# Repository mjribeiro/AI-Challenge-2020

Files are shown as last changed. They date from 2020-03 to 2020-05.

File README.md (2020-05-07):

# Citizen Data Science: Exploring the use of machine learning for a public network of low-cost air quality devices

Might add/change this information to be about our project specifically, but for now I think the general description and some assignment guidelines should be helpful for keeping track of deadlines and structuring submissions :)

## Assignment Description
This is the repository for the report and code for a group project for the CM50304 unit. The provided coursework description is as follows:

> As  a  group  you  will  need  to  choose  a  challenge related  to  artificial  intelligence  (AI), propose  a  solution  to  it, develop  a  prototype  or  a  proof  of  concept for  this  solution,  and  critically evaluate  this  solution  in  terms  of  how  it  meets  accountability,  responsibility  and  transparency concerns. 
>
> It can be a challenge in AI development such as challenges in ensuring fairness in AI decisions, or it can be a societal challenge that can be solved with AI such as dangerous search and rescue operations that can be performed by robots, or it can be a societal challenge created by AI such as challenges in ensuring truth in media content in the presence of deepfakes and news articles generated by AI.
>
> The choice of challenges is unlimited as long as you can justify that this is an important challenge for the society. It can be either directly essential to the society because, for example, it addresses urgent societal needs, or the challenge may be important indirectly to society because, for example, solution of this challenge would improve business processes and as a consequence it would bring improvements for the overall society.

## Assessments
|Task |% of Mark | Date & Time |Done? (Y/N)| 
|---|---|---|---|
|Prototype |0? |20/04/2020, 17:15 |Y |
|Prototype Demo|20 |04/05/2020, 14:15-16:05|Y | 
|Written Report|80 |08/05/2020, 16:00 |Y | 

### Demo and Presentation (20%)
Maximum 5 min demonstration of prototype, followed by 20 min presentation with 5 min of questioning. The presentation should cover:
* What is the challenge and why it is important
* What is the state of the art for this challenge
* What is the solution
* What is the prototype
* What is the future work to develop the whole solution
* How does the solution meet accountability, responsibility and transparency concerns

### Written report (80%)
The report should follow this structure:
1. **Title and list of team members** (*1 page*) – the report should not be anonymous because the project would be demonstrated in person in advance
2. **Problem specification of the challenge** (*0.5 – 1 page*) – this section should state the challenge, motivate why this challenge is important and explain how it relates to AI
3. **State of the art review** (*2 – 3 pages*) – this section should review the existing solutions for this challenge and critical analyse ethical issues related to them. It maybe the case that there are no existing solutions for the  chosen challenge. In this case this should be clearly stated and analysed why it is so. If applicable, existing solutions for related challenges may be reviewed here. For example, if your solution is based on solutions for other challenges you  should review and critically analyse them in this section.
4. **Whole solution description** (*1 – 3 pages*) – this section should explain your ambitious solution and why it requires or why it benefits from the interdisciplinary approach. If the solution involves novel research the section should explain why you believe that this research is likely to be successful in the foreseeable future (see above).
5. **Prototype description** (*3 – 10 pages*) – this section should explain the scope of your developed prototype, explain how it  works and how it relates to the whole solution. It should clearly demonstrate the interdisciplinary effort in this development. If interdisciplinary development was not possible (see above) it should be clearly stated in this section and explain why it was not possible to exploit some of the expertise from members of your group. This section should also reflect how the experience of  developing this prototype has confirmed or questioned your whole solution and how it may have changed your view on the whole solutionor possiblythe challenge in general.
6. **Plan for the future work to develop the solution** (*0.5 – 1 page*) – this section should describe immediate and long-term steps after development of the prototype that should be made to achieve  the  whole  solution. If during development of prototype or  critical  reflection  of  the solution you come to the conclusion that the proposed solution is not useful or not ethically responsible or the overall challenge should not  be formulated in this way (see  above), this section should clearly state this case and may omit description of future work.
7. **Critical reflection of the solution** (*1 – 3 pages*) – this section should provide an analyse how the proposed solution  meets  accountability,  responsibility,  transparency  and  other  ethical concerns. It should honestly reflecton both positive and  negative impac  the solution may ave.If the view from the ethical perspective on the solution has changed during the work on this project this section should describe that and explain why the view has changed.
8. **Teamwork  process  description**  (*2 – 3  pages*) – this section should  describe how your group organised teamwork, what communication channels and collaboration tools you used, how you distributed the tasks, what process allowed you to learn from another discipline during this project.
9. **Lessons learnt**  (*1 – 2 pages*) – this section should reflect on the whole project from the teamwork perspective: what was done well, what could have been improved, what would you change if you were to work on another project in this group, what could you recommend for an interdisciplinary team.
10. **Individual   contributions**   (*1 – 2 pages*) – this section should briefly state individual contributions from each team member.
11. **Lessons learnt from another discipline** (*0.5 – 1 page per person*) – each member of the group should state what they learnt from another discipline during this project.

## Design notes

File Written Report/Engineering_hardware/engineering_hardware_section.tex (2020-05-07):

\subsection{Device}

%\subsection{Design Requirements:}

\textbf{Design Specification}\\

% Table generated by Excel2LaTeX from sheet 'Sheet1'
\begin{table}[htbp]
  \centering
  \caption{Add caption}
\resizebox{\textwidth}{!}{\begin{tabular}{lccll}
\hline
    \multicolumn{1}{c}{No.}&{Requirement} & Wish/Deman & \multicolumn{1}{p{10.785em}}{Importance} & \multicolumn{1}{c}{Engineering Specification}  \\
          &       & \multicolumn{1}{p{8.785em}}{ (1 low, 5 high)} &       &  \\
\hline
1& Sensors open to atmosphere & D & & \\
2&Water Proof & D & & IP67 \\
3&Long battery life & W & 4 & Self powered + battery capacity. > 1 week battery life \\
4&Easy to set up & W & 5 & \\
5&Durable & W & 4 & Sustain accidental drops from height 0.5m \\
6&Low cost & W & 3 & Component and raw material cost < £200 \\
7&Recylable & W & 2 & \\
8&Transparent & W & 4 & \\
9&Easy to charge & W & 2 & Clear acess to charging port \\
10&Cheap to manufacture & W & 3 & Manufacture and assembly cost < £30 \\
11&Small form factor & W & 3 & Overall dimmensions 30x30x30cm \\
\hline
\end{tabular}}%
\label{tab:specification}
\end{table}%

Long Battery Life (4):\\
To ensure regular air quality measurements minimum intervention with the device is required. The most involved element is the charging of the device, therefore this should be kept to a minimum by having a long battery life.
\vskip 0.1in
Easy to set up (5):\\
Crucial to ensuring a citizen science approach to monitoring air quality is maintaining a very simple set up of the sensor. As stipulated in the background the device must be portable and thus require 'packing up' and 'setting up'. Therefore both of these processes must be intuitive (completable without any training or instruction).
\vskip 0.1in
Durable (4):\\
Due to the portable nature of the sensor, and to ensure longevity, the device must be durable to general wear and tear. This has the added benefit of reducing the cost of the air monitoring system by extending the useable life of each sensor.
\vskip 0.1in
Low Cost (3:)\\
In line with the goals of a low cost widely distributed sensor network, the manufacture and component costs must be kept to a minimum to ensure affordability of the device.
\vskip 0.1in
Recyclable (2):\\
In line with responsible use of AI the physical device should not contribute to environmental concerns. This will be achieved by avoiding non-recyclable materials in the design process where possible. These include styrofoam, black plastics and bi-material composites which are hard to separate in the recycling process.
\vskip 0.1in
Transparent (4):\\
The concept of transparent AI can also be extended to the physical device. Ability to view the electronics will demonstrate there are no other devices present such as camera and microphones. An accompanying schematic could be displayed on the website on which the air quality data is displayed. This would detail the components and their purposes in lay terms, which the transparent device would then allow confirmation upon inspection.
\vskip 0.1in
Easy to charge (2):\\
To engage in citizen science effectively, the device should be easy to charge.
\vskip 0.1in
Cheap to manufacture (3):\\
In addition to component cost, the manufacture methods can add considerable cost. Therefore the design should incorporate modularity and simplicity resulting in a minimum number of different manufacturing processes to reduce cost.
\vskip 0.1in
Small form factor (3):\\
The device must be suitable for a variety of different locations, and not take up valuable garden or indoor space.\\
\vskip 0.1in
\textbf{Concepts}\\

A wide variety of concepts were generated using a brainstorming approach. Different design cues and ideas were incorporated into four overall concepts, these are displayed below with key features labelled:

\begin{figure}[H]
\centering
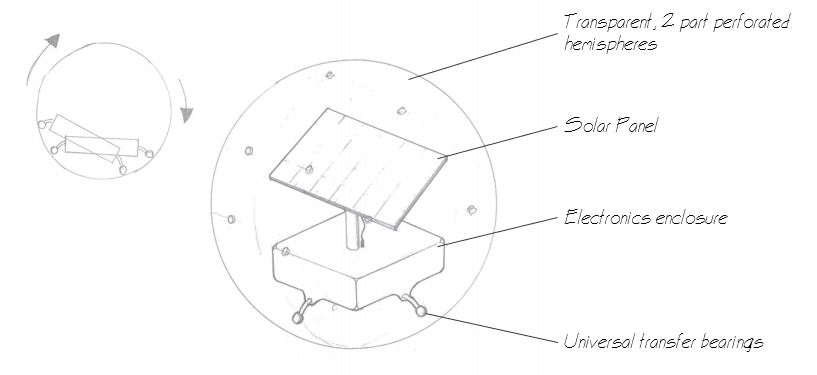
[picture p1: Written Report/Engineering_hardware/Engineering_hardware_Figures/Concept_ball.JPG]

\caption{\textbf{Concept A:} A clear sphere surrounds the sensor hardware, the symmetry of the sphere allows the sensors to move within the protective casing. This concept is focused on the specification requirement for easy setup, the self-levelling mechanism ensures a solar panel for charging is always facing up to the light, whilst sensors can be open to the environment and protected from rain by always facing down. }
\label{fig:concept_A}
\end{figure}

\begin{figure}[H]
\centering
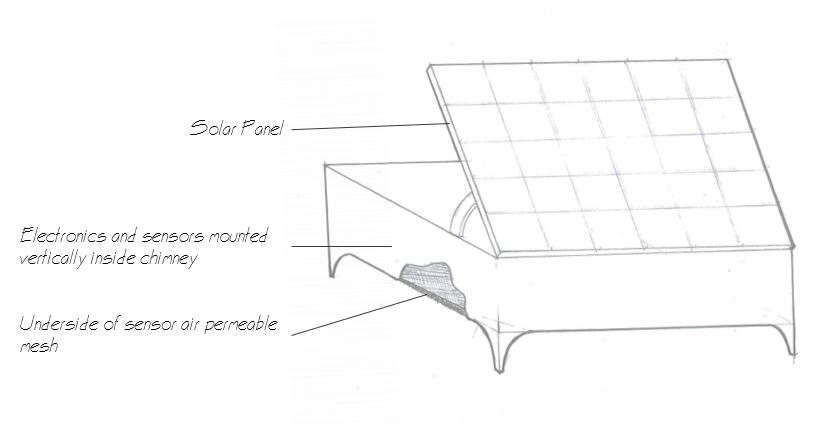
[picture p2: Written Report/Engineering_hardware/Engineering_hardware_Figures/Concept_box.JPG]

\caption{\textbf{Concept B:} A solid box contains the sensors, open to the environment and protected from water ingress by a casing raised on small legs. This concept is focused on the specification requirement for low cost; at each stage the design was simplified as much as possible to reduce component cost and simplify the manufacturing and assembly.}
\label{fig:concept_B}
\end{figure}

\begin{figure}[H]
\centering
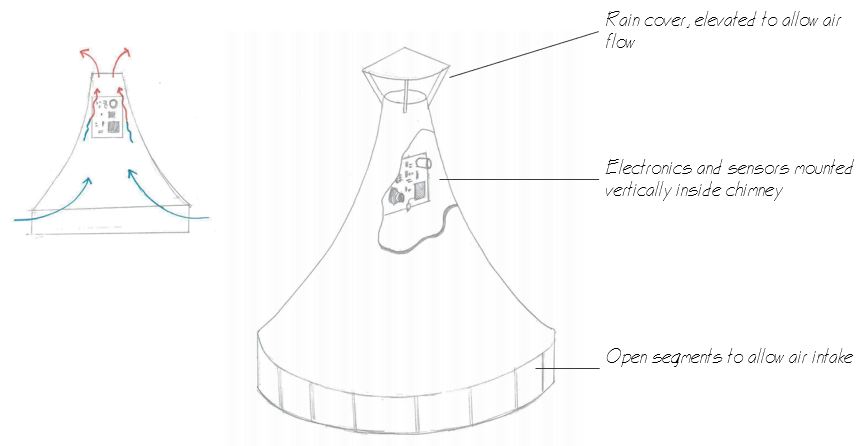
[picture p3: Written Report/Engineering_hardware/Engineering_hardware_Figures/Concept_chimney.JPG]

\caption{\textbf{Concept C:} The electronics and sensors are encased in a chimney-like structure. This concept was inspired by using natural convection currents driven by heat given off by the electronics to drive air past the sensors. This solution would be an energy-efficient method for making accurate measurements without the use of an electric fan.}
\label{fig:15cm_shell_loading}
\end{figure}

\begin{figure}[H]
\centering
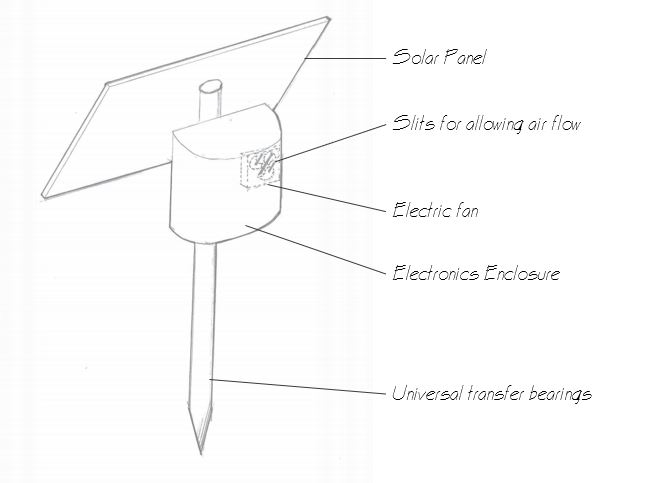
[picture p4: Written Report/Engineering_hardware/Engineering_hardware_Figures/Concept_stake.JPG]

\caption{C\textbf{Concept D:} A protective case houses the sensors and electronics, a larger solar panel is used to power an electric fan which feeds air into the sensors. This design is a larger more robust concept of an air quality monitor with a less portable design.}
\label{fig:15cm_shell_loading}
\end{figure}

The four concepts described were then scored against the design criteria specified in table \ref{tab:specification}. The "demand" categories were simple boolean pass-fail criteria. The "wish" categories were given a numeric score 1-5 with five being the best dependant on how well the concept met the specification, this was weighted by the importance of each specification point and summed to give an overall score.

% Table generated by Excel2LaTeX from sheet 'Sheet1'
\begin{table}[htbp]
  \centering
  \caption{Add caption}
    \begin{tabular}{lrrrr}
          & \multicolumn{4}{c}{Concepts} \\
\hline
    Spec No. & \multicolumn{1}{l}{A} & \multicolumn{1}{l}{B} & \multicolumn{1}{l}{C} & \multicolumn{1}{l}{D} \\
\hline
    \multicolumn{1}{r}{1} & 1     & 1     & 1     & 1 \\
    \multicolumn{1}{r}{2} & 1     & 1     & 1     & 1 \\
    \multicolumn{1}{r}{3} & 3     & 5     & 2     & 4 \\
    \multicolumn{1}{r}{4} & 5     & 4     & 3     & 1 \\
    \multicolumn{1}{r}{5} & 5     & 3     & 4     & 3 \\
    \multicolumn{1}{r}{6} & 4     & 5     & 2     & 3 \\
    \multicolumn{1}{r}{7} & 3     & 3     & 3     & 3 \\
    \multicolumn{1}{r}{8} & 5     & 4     & 5     & 3 \\
    \multicolumn{1}{r}{9} & 3     & 5     & 3     & 4 \\
    \multicolumn{1}{r}{10} & 3     & 4     & 2     & 3 \\
    \multicolumn{1}{r}{11} & 4     & 4     & 3     & 2 \\
    weighted sum & \cellcolor[rgb]{ .388,  .745,  .482}127 & \cellcolor[rgb]{ .427,  .757,  .486}126 & \cellcolor[rgb]{ .98,  .616,  .459}96 & \cellcolor[rgb]{ .973,  .412,  .42}86 \\
\hline
    \end{tabular}%
  \label{tab:addlabel}%
\end{table}%

The weighted comparison between concepts revealed that concept A was most suitable for fulfilling the design brief. Prototype B was very close in the overall score however prototype A was perceived to have a few key advantages:
\begin{itemize}
\item A round spherical casing has no localised stress concentrations as opposed to a more angular geometry of prototype B. The sensor would be more robust to impact fractures that it would be exposed to from being dropped.
\item Concept A has a significantly more appealing design in terms of interesting aesthetic and movable internal parts. Although hard to quantify and therefore not included as design criteria, engaging design is more likely to interest the public for citizen science initiatives.
\item The self-levelling design of concept A, although adding some cost ensures the sensor cannot be setup incorrectly, the reliability of readings that this would likely produce is likely to outweigh a small increase in cost.
\end{itemize}

%prototypes for each mechanism:
%locking two parts together

\textbf{Prototype}\\

A prototype was designed and built to test the suitability of the design, the form of the device was designed as a single 3d printed piece. 3d printing is an industry-standard for rapid prototyping, a PLA plastic material was used due to its low melting point and hence high-quality finish. An "off the shelf" Polystyrene, transparent, 180 mm diameter sphere was specified for the casing:
\begin{figure}[H]
\centering
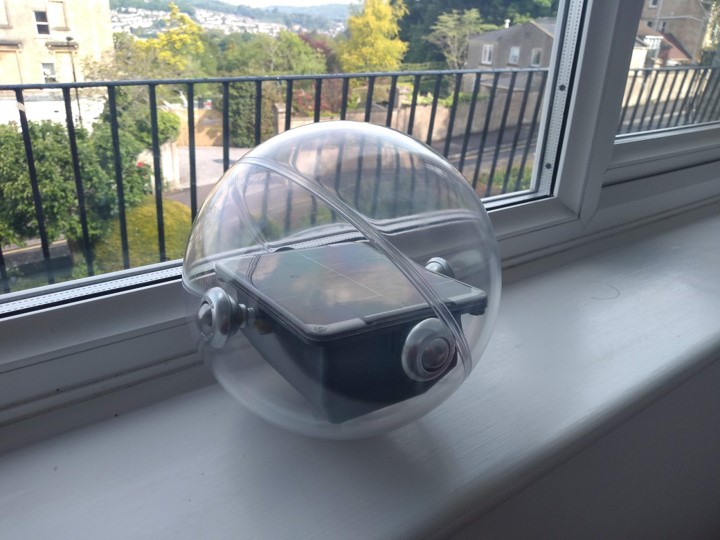
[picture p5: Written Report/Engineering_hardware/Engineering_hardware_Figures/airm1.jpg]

\caption{The physical prototype, displayed in a typical setting on a window sill.}
\label{fig:15cm_shell_loading}
\end{figure}

A 6W solar panel was chosen as the maximum surface area that could be accommodated by a device of this size. The prototype included a lithium-ion battery chosen for high capacity compared with size and weight. In addition, a UBEC power converter was used to handle the different voltages from solar panel and battery stepping down to 5V as standard for most small DC electronics including Raspberry Pi single-board computer. 19mm universal bearing were chosen to provide a frictionless interface between the sphere and the electronics casing. A large diameter was chosen to reduce interference between the perforations in the sphere and the movement of the electronics case.

\begin{figure}[H]
\centering
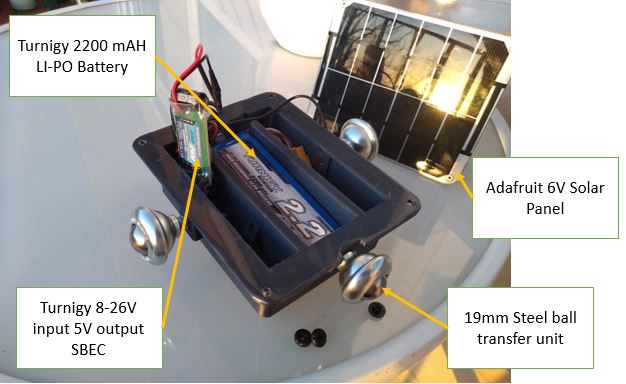
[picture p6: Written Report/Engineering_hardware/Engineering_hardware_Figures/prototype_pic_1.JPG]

\caption{Underneath the waterproof solar panel the electronics including battery and power distribution are housed }
\label{fig:15cm_shell_loading}
\end{figure}

A raspberry Pi 3 was used to simulate the custom PCB and sensors developed for this device. The Rasberry Pi runs a Linux operating system which can be interfaced with remotely over WiFi. Power was supplied by a USB-C connection connected to the battery circuitry. The GPIO pins on the Raspberry Pi can be used to interface with other hardware devices. An SGP30 gas sensor was attached to the GPIO pins to produce air quality measurements. To make gas measurements i2c messages were passed to the relevant bus address at a frequency of 1Hz. This was implemented with a Python script run on the Raspberry Pi.

\begin{figure}[H]
\centering
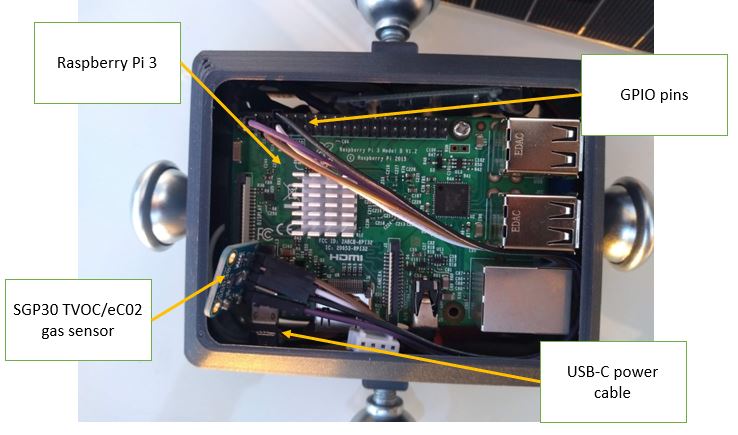
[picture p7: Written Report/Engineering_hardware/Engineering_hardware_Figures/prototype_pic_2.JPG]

\caption{The underside of the electronics case is open to the envoronment to allow sensors to measure the air quality.}
\label{fig:15cm_shell_loading}
\end{figure}

%MOVE TO APPENDIX:
\includepdf[pages={-},fitpaper,rotateoversize]{Engineering_hardware/prototype_air_quality_monitor_case.pdf}

\textbf{Evaluation of prototype:}\\
The prototype provided valuable lessons that influenced the final device design. The need for custom electronics was apparent due to the space requirement of many components and their associated wiring. Additionally, the thickness of the sphere was an important consideration since the weight of the device was sufficient to warp the sphere at the points of applied pressure. This warping was problematic since the universal bearing based design was dependant on equal dimensions along both axes to ensure smooth movement.

It was decided to change the design to use a circular frame attached to the spherical case using ball bearings allowing pivoting along one axis. The electronics case is then attached to the frame perpendicular to the first axis of rotation, and free to pivot using a second pair of ball bearings. As before the electronics case will self-level since the centre of mass is below the pivot point, however, the warping of the sphere will not impede the rotation since it is only in contact at two points.

To design a tolerance that would minimise the size of the device whilst allowing for warping of the spherical case finite element analysis was carried out on the case. The resulting distortion was quantified and a slightly larger tolerance chosen to avoid interference.

\begin{figure}[H]
\centering
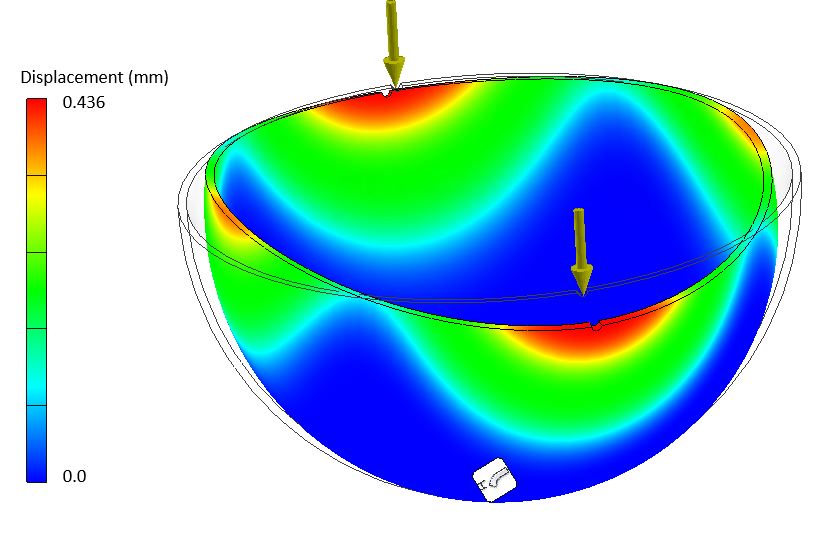
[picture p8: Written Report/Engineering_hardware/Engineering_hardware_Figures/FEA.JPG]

\caption{Finite element analysis reveals the extent of deformation experienced under loading from the device mass. This was used to define the tolerence of the self-levelling frame to avoid inteference.}
\label{fig:15cm_shell_loading}
\end{figure}

\textbf{Final Design}
A prototype design was incrementally improved to produce a final design. This includes a wider use of materials, custom parts and manufacturing techniques not available for a rapidly prototyped design but suitable for cost-effective large scale manufacture. The final design was rendered in a photo-realistic environment to give an impression of the final product:

\begin{figure}[H]
\centering
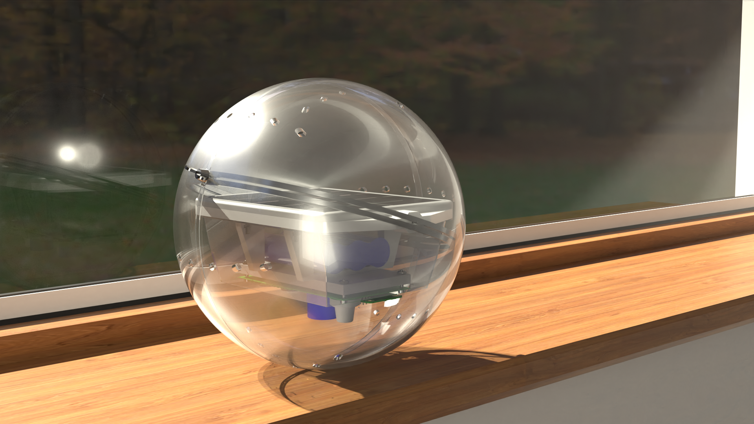
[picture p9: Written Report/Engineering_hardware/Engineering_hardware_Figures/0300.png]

\caption{Photo realistic render of the final air quality monitoring device. }
\label{fig:15cm_shell_loading}
\end{figure}
The notable changes from the prototype design are:
\begin{itemize}
\item Mechanism for self-levelling changed to two-axis design.
\item Battery capacity upgraded to 6600mAH
\item Custom PCB for electronics and sensors
\item Electronics casing updated to multiple mass-producible components as opposed to single 3d printed structure.
\end{itemize}
An exploded-view lists all the components that make up the device, and demonstrates the hierarchy of components into an assembly:

\includepdf[pages={-},fitpaper,rotateoversize]{Engineering_hardware/assembly-1-2_exploded.pdf}

\textbf{Design for Manufacture}\\
The form and material of parts have been carefully considered to provide the required characteristics whilst being mass producible with a simple method for manufacture to reduce cost. Each custom made part has its manufacturing method detailed numbering is per the exploded view:
\begin{itemize}
\item Item 1: Top plate is laser cut from 6mm acrylic. 6mm is a standard thickness of the acrylic sheet, this manufacturing method is very adaptable allowing design changes to be incorporated without any expensive re-tooling. This manufacturing could be easily transferred to injection moulding once sufficient production throughput is required. Post-processing requires countersinking for screw heads, this can be performed by hand or easily automated with a multiheaded attachment to the laser-cutting machine.
\item Item 3: Same as 1.
\item Item 4: Laser cut part (same motivation as part 1) in addition high tolerance of laser-cut part allows for interference fit reducing amount of adhesive required.
\item Item 6: Mild steel was used for the frame as an inexpensive machinable material with sufficient stiffness. The part can be laser cut from steel sheets or cold rolled and welded depending on production capacity required. Anadosing or powder coating would then be applied to produce weatherproofing.
\item Item 14: Same as 1.
\item Item 15: Weather skirt is a non-load bearing transparent part, deep drawing is a suitable manufacturing method for mass-producing moulded thin parts from transparent materials such a polyethylene.
\item Item 20: Dome (two parts), production of this part is likely to be outsourced to a manufacturer specialised in making polystyrene domes. There will be some capital cost for tooling, manufacturing method will be dictated by the supplier but likely to be drawing or vacuum forming, both suitable for mass production.
\end{itemize}

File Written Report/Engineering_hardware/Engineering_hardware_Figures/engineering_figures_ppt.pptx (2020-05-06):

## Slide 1

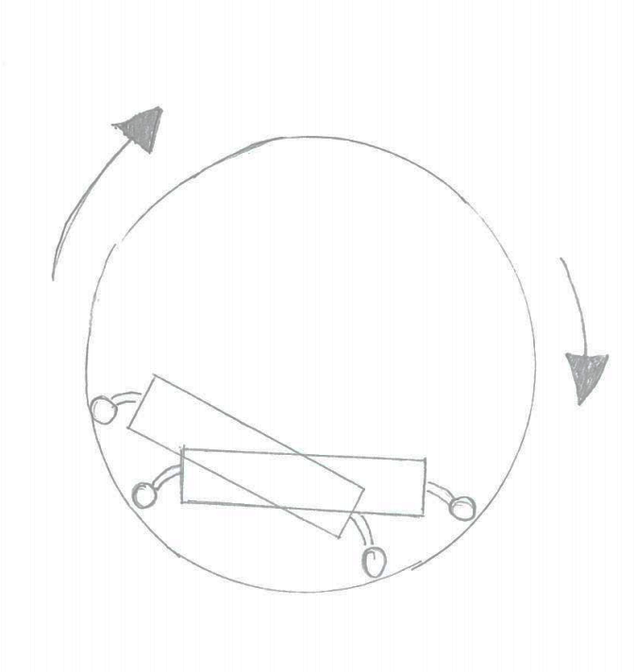
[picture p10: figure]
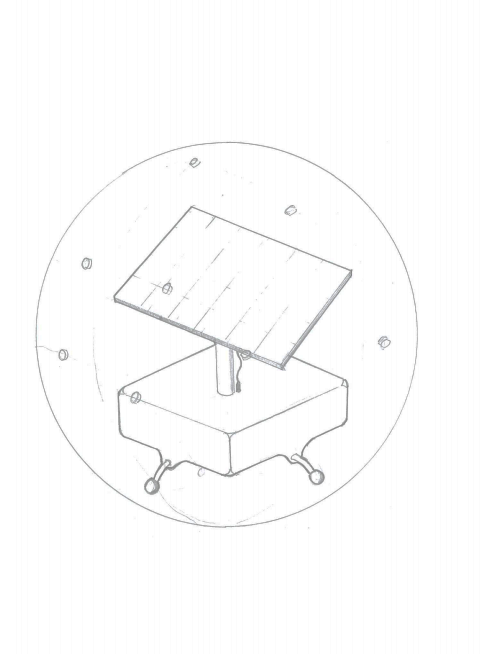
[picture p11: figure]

Transparent, 2 part perforated hemispheres

Solar Panel

Electronics enclosure

Universal transfer bearings

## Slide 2

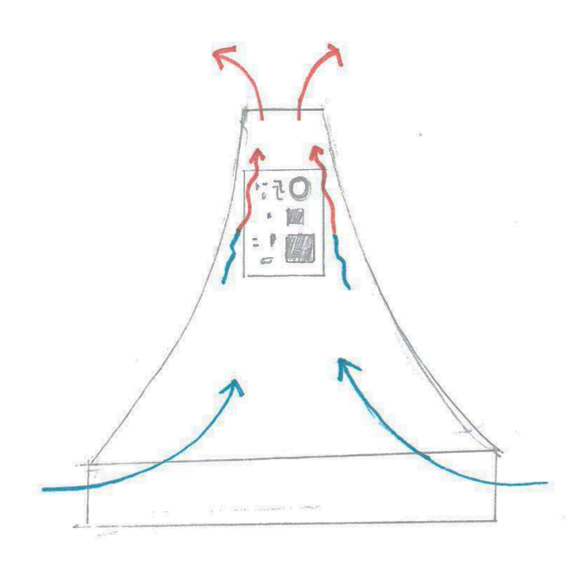
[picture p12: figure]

Rain cover, elevated to allow air flow

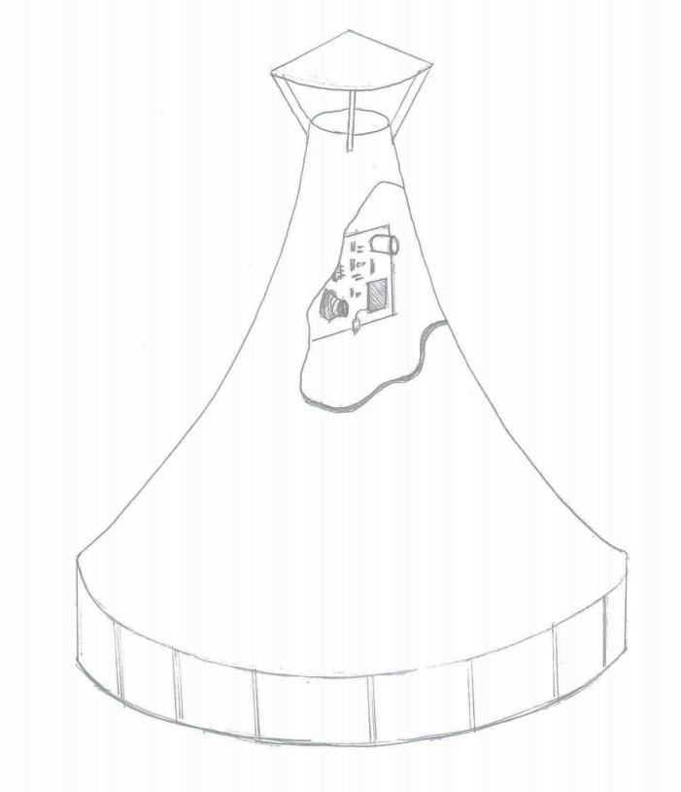
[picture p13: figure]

Electronics and sensors mounted vertically inside chimney

Open segments to allow air intake

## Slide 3

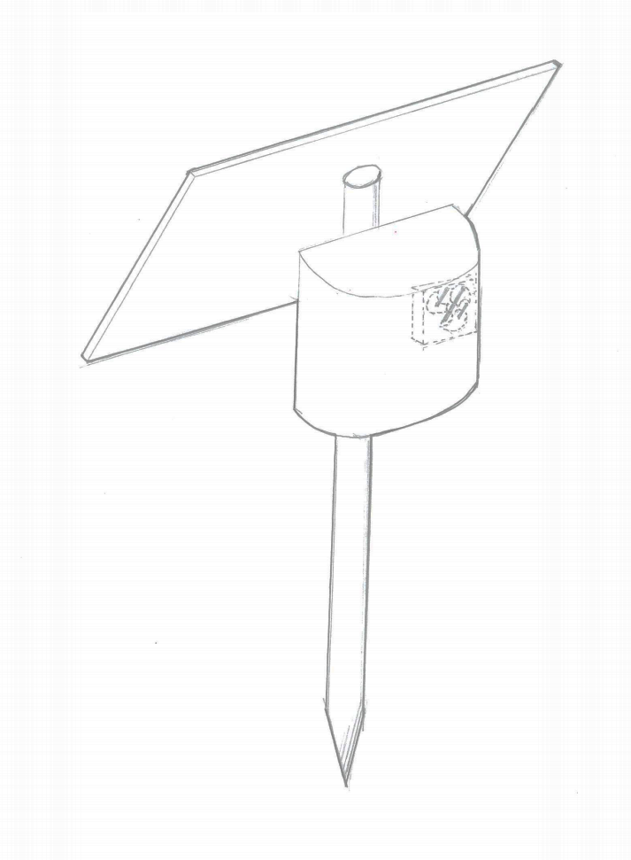
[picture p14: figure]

Solar Panel

Slits for allowing air flow

Electric fan

Electronics Enclosure

Universal transfer bearings

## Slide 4

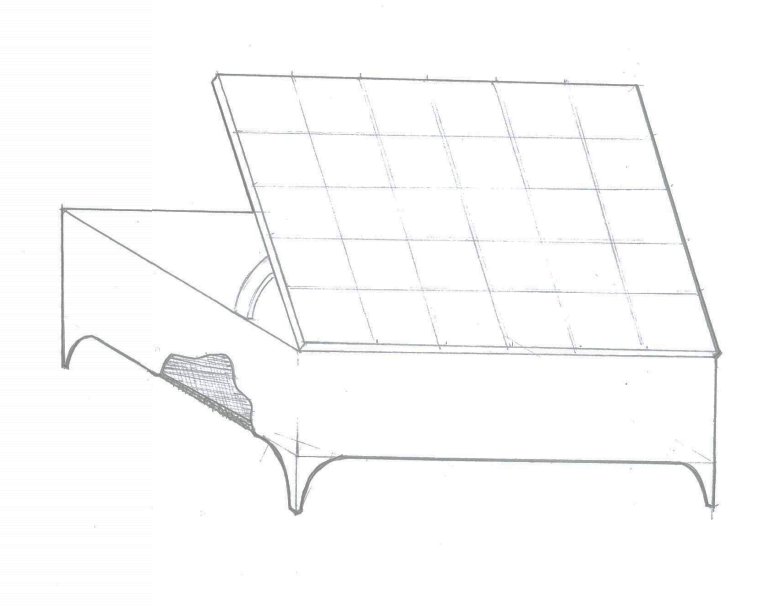
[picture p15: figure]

Solar Panel

Electronics and sensors mounted vertically inside chimney

Underside of sensor air permeable mesh

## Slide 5

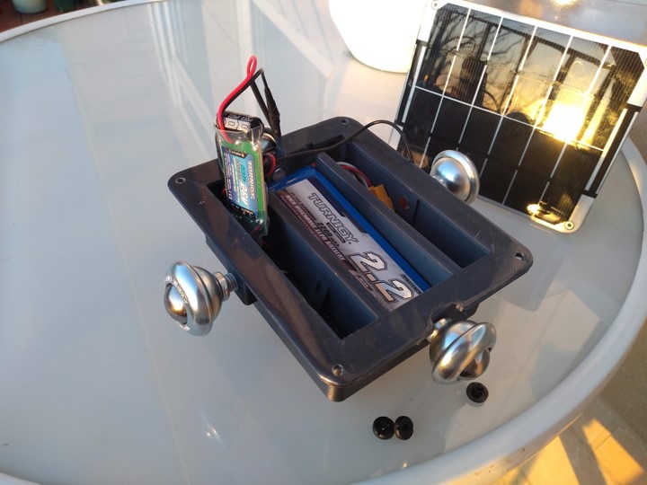
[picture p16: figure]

Turnigy 2200 mAH LI-PO Battery

Adafruit 6V Solar Panel

Turnigy 8-26V input 5V output SBEC

19mm Steel ball transfer unit

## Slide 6

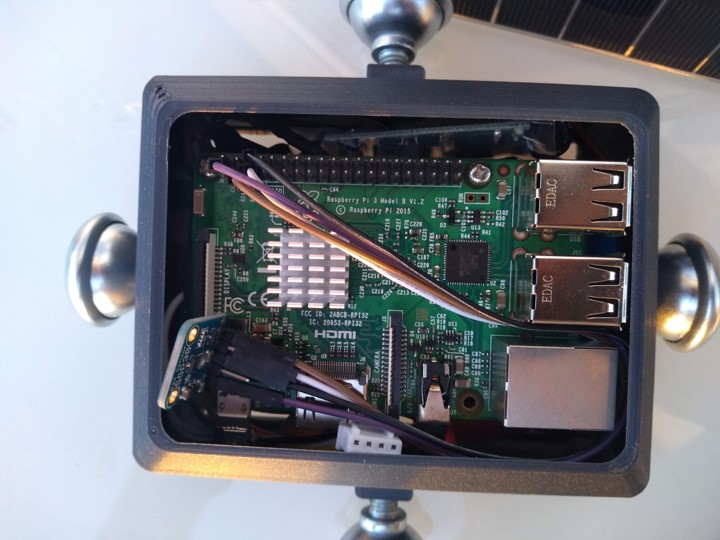
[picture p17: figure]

Raspberry Pi 3

GPIO pins

SGP30 TVOC/eC02 gas sensor

USB-C power cable

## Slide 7

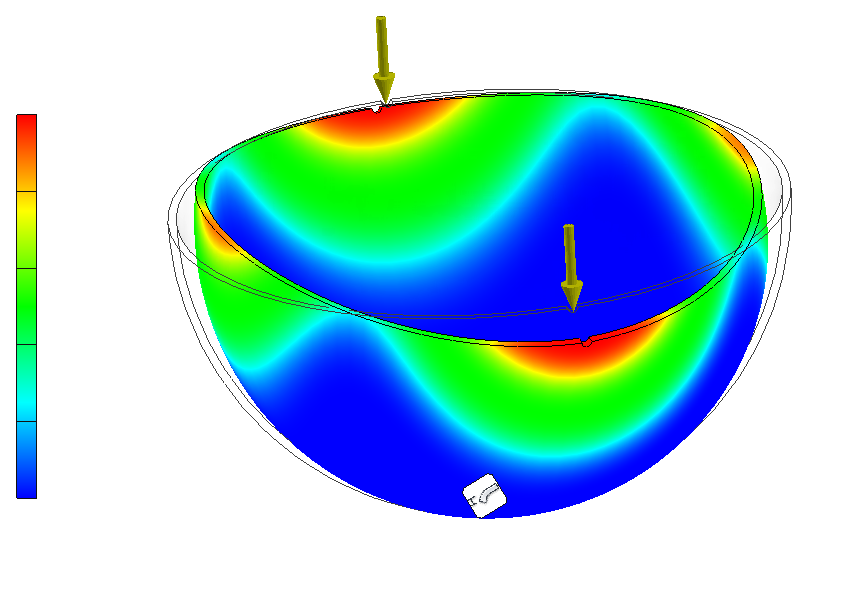
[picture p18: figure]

Displacement (mm)

0.436

0.0

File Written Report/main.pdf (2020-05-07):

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

## 1. Summary

[Briey describe the goal of the project.]

1

## 2. Problem denition and background

## 2.1 Problem specication

[This section should state the challenge, motivate why this challenge is important and explain how it relates to AI.]

## 2.2 Literature review

[This section should review the existing solutions for this challenge and critically analyse ethical issues related to them. It is maybe the case that there are no existing solutions for the chosen challenge. In this case this should be clearly stated and analysed why it is so. If applicable, existing solutions for related challenges may be reviewed here. For example, if your solution is based on solutions for other challenges you should review and critically analyse them in this section.]

## 2.3 Proposed solution

[This section should explain your ambitious solution and why it requires or why it benets from the interdisciplinary approach. If the solution involves novel research the section should explain why you believe that this research is likely to be successful in the foreseeable future (see above).]

2

## 3. Air quality monitoring device

[Describe the engineering part of the project.]

## 3.1 Hardware

3.1.1 Device

Design Specication

Table 3.1: Add caption

No. | Requirement | Wish/Deman | Importance | Engineering Specication
| | (1 low, 5 high)
1 | Sensors open to atmosphere | D
2 | Water Proof | D | | IP67
3 | Long battery life | W | 4 | Self powered + battery capacity. > 1 week battery life
4 | Easy to set up | W | 5
5 | Durable | W | 4 | Sustain accidental drops from height 0.5m
6 | Low cost | W | 3 | Component and raw material cost < ¿200
7 | Recylable | W | 2
8 | Transparent | W | 4
9 | Easy to charge | W | 2 | Clear acess to charging port
10 | Cheap to manufacture | W | 3 | Manufacture and assembly cost < ¿30
11 | Small form factor | W | 3 | Overall dimmensions 30x30x30cm

Long Battery Life (4):
To ensure regular air quality measurements minimum intervention with the device is required. The most involved element is the charging of the device, therefore this should be kept to a minimum by having a long battery life.

Easy to set up (5):
Crucial to ensuring a citizen science approach to monitoring air quality is maintaining a very simple set up of the sensor. As stipulated in the background the device must be portable and thus require 'packing up' and 'setting up'. Therefore both of these processes must be intuitive (completable without any training or instruction).

Durable (4):
Due to the portable nature of the sensor, and to ensure longevity, the device must be durable to general wear and tear. This has the added benet of reducing the cost of the air monitoring system by extending the useable life of each sensor.

Low Cost (3:)

3

In line with the goals of a low cost widely distributed sensor network, the manufacture and component costs must be kept to a minimum to ensure aordability of the device.

Recyclable (2):
In line with responsible use of AI the physical device should not contribute to environmental concerns. This will be achieved by avoiding non-recyclable materials in the design process where possible. These include styrofoam, black plastics and bi-material composites which are hard to separate in the recycling process.

Transparent (4):
The concept of transparent AI can also be extended to the physical device. Ability to view the electronics will demonstrate there are no other devices present such as camera and microphones. An accompanying schematic could be displayed on the website on which the air quality data is displayed. This would detail the components and their purposes in lay terms, which the transparent device would then allow conrmation upon inspection.

Easy to charge (2):
To engage in citizen science eectively, the device should be easy to charge.

Cheap to manufacture (3):
In addition to component cost, the manufacture methods can add considerable cost. Therefore the design should incorporate modularity and simplicity resulting in a minimum number of dierent manufacturing processes to reduce cost.

Small form factor (3):
The device must be suitable for a variety of dierent locations, and not take up valuable garden or indoor space.

Concepts

A wide variety of concepts were generated using a brainstorming approach. Dierent design cues and ideas were incorporated into four overall concepts, these are displayed below with key features labelled:


Figure 3.1: Concept A: A clear sphere surrounds the sensor hardware, the symmetry of the sphere allows the sensors to move within the protective casing. This concept is focused on the specication requirement for easy setup, the self-levelling mechanism ensures a solar panel for charging is always facing up to the light, whilst sensors can be open to the environment and protected from rain by always facing down.

4


Figure 3.2: Concept B: A solid box contains the sensors, open to the environment and protected from water ingress by a casing raised on small legs. This concept is focused on the specication requirement for low cost; at each stage the design was simplied as much as possible to reduce component cost and simplify the manufacturing and assembly.


Figure 3.3: Concept C: The electronics and sensors are encased in a chimney-like structure. This concept was inspired by using natural convection currents driven by heat given o by the electronics to drive air past the sensors. This solution would be an energy-ecient method for making accurate measurements without the use of an electric fan.

5


Figure 3.4: CConcept D: A protective case houses the sensors and electronics, a larger solar panel is used to power an electric fan which feeds air into the sensors. This design is a larger more robust concept of an air quality monitor with a less portable design.

The four concepts described were then scored against the design criteria specied in table 3.1. The "demand" categories were simple boolean pass-fail criteria. The "wish" categories were given a numeric score 1-5 with ve being the best dependant on how well the concept met the specication, this was weighted by the importance of each specication point and summed to give an overall score.

Table 3.2: Add caption

Concepts
Spec No. | A | B | C | D
1 | 1 | 1 | 1 | 1
2 | 1 | 1 | 1 | 1
3 | 3 | 5 | 2 | 4
4 | 5 | 4 | 3 | 1
5 | 5 | 3 | 4 | 3
6 | 4 | 5 | 2 | 3
7 | 3 | 3 | 3 | 3
8 | 5 | 4 | 5 | 3
9 | 3 | 5 | 3 | 4
10 | 3 | 4 | 2 | 3
11 | 4 | 4 | 3 | 2
weighted sum | 127 | 126 | 96 | 86

The weighted comparison between concepts revealed that concept A was most suitable for fullling the design brief. Prototype B was very close in the overall score however prototype A was perceived to have a few key advantages:

| A round spherical casing has no localised stress concentrations as opposed to a more angular geometry
| 6

of prototype B. The sensor would be more robust to impact fractures that it would be exposed to from being dropped.

| Concept A has a signicantly more appealing design in terms of interesting aesthetic and movable internal parts. Although hard to quantify and therefore not included as design criteria, engaging design is more likely to interest the public for citizen science initiatives.
| The self-levelling design of concept A, although adding some cost ensures the sensor cannot be setup incorrectly, the reliability of readings that this would likely produce is likely to outweigh a small increase in cost.

Prototype

A prototype was designed and built to test the suitability of the design, the form of the device was designed as a single 3d printed piece. 3d printing is an industry-standard for rapid prototyping, a PLA plastic material was used due to its low melting point and hence high-quality nish. An "o the shelf" Polystyrene, transparent, 180 mm diameter sphere was specied for the casing:


Figure 3.5: The physical prototype, displayed in a typical setting on a window sill.

A 6W solar panel was chosen as the maximum surface area that could be accommodated by a device of this size. The prototype included a lithium-ion battery chosen for high capacity compared with size and weight. In addition, a UBEC power converter was used to handle the dierent voltages from solar panel and battery stepping down to 5V as standard for most small DC electronics including Raspberry Pi single-board computer. 19mm universal bearing were chosen to provide a frictionless interface between the sphere and the electronics casing. A large diameter was chosen to reduce interference between the perforations in the sphere and the movement of the electronics case.

7


Figure 3.6: Underneath the waterproof solar panel the electronics including battery and power distribution are housed

A raspberry Pi 3 was used to simulate the custom PCB and sensors developed for this device. The Rasberry Pi runs a Linux operating system which can be interfaced with remotely over WiFi. Power was supplied by a USB-C connection connected to the battery circuitry. The GPIO pins on the Raspberry Pi can be used to interface with other hardware devices. An SGP30 gas sensor was attached to the GPIO pins to produce air quality measurements. To make gas measurements i2c messages were passed to the relevant bus address at a frequency of 1Hz. This was implemented with a Python script run on the Raspberry Pi.


Figure 3.7: The underside of the electronics case is open to the envoronment to allow sensors to measure the air quality.

8

1

2

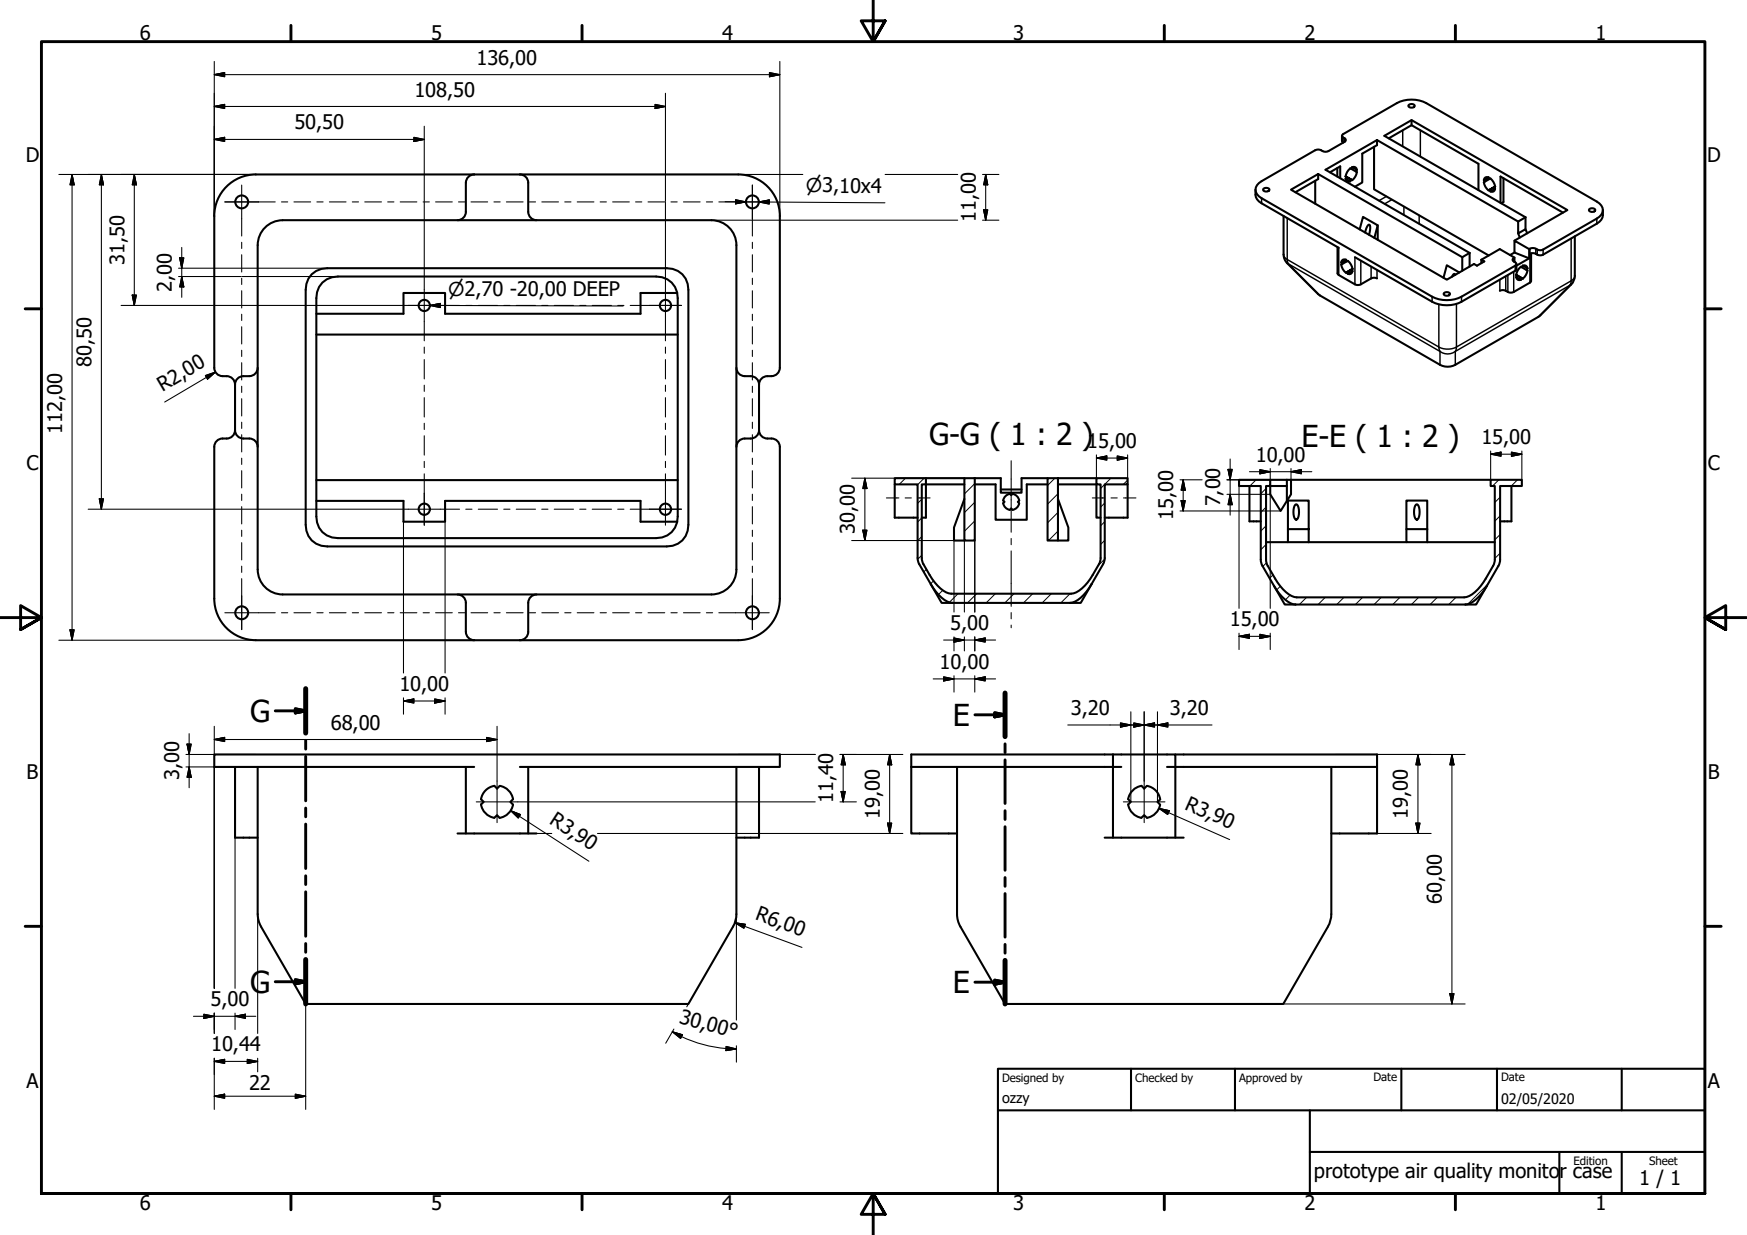
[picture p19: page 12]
ozzy; Designed by; Checked by; Approved by; Date; Edition; Sheet; P2,70 -20,00 DEEP

prototype air quality monitor case

Evaluation of prototype:
The prototype provided valuable lessons that inuenced the nal device design. The need for custom electronics was apparent due to the space requirement of many components and their associated wiring. Additionally, the thickness of the sphere was an important consideration since the weight of the device was sucient to warp the sphere at the points of applied pressure. This warping was problematic since the universal bearing based design was dependant on equal dimensions along both axes to ensure smooth movement.
It was decided to change the design to use a circular frame attached to the spherical case using ball bearings allowing pivoting along one axis. The electronics case is then attached to the frame perpendicular to the rst axis of rotation, and free to pivot using a second pair of ball bearings. As before the electronics case will self-level since the centre of mass is below the pivot point, however, the warping of the sphere will not impede the rotation since it is only in contact at two points.
To design a tolerance that would minimise the size of the device whilst allowing for warping of the spherical case nite element analysis was carried out on the case. The resulting distortion was quantied and a slightly larger tolerance chosen to avoid interference.


Figure 3.8: Finite element analysis reveals the extent of deformation experienced under loading from the device mass. This was used to dene the tolerence of the self-levelling frame to avoid inteference.

Final Design A prototype design was incrementally improved to produce a nal design. This includes a wider use of materials, custom parts and manufacturing techniques not available for a rapidly prototyped design but suitable for cost-eective large scale manufacture. The nal design was rendered in a photo-realistic environment to give an impression of the nal product:

10

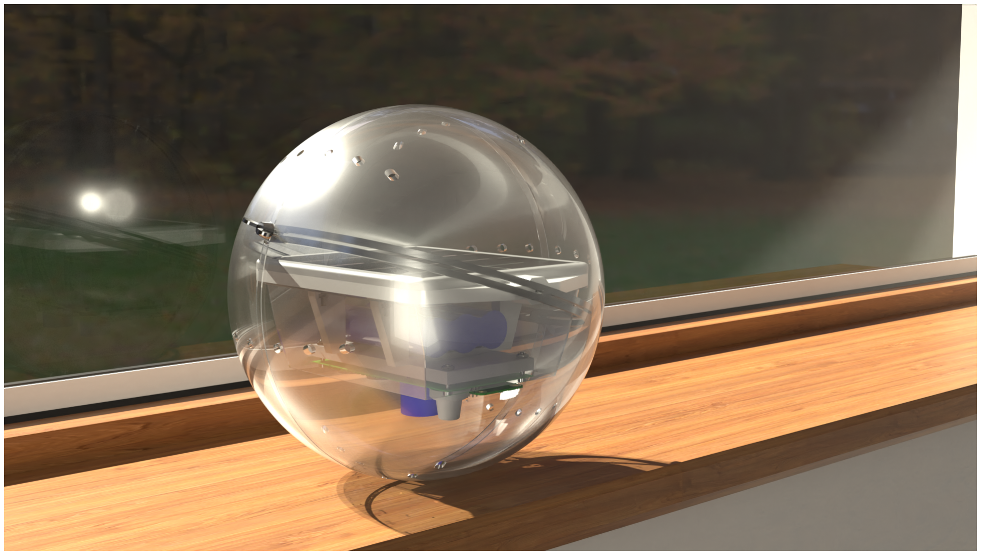
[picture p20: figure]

Figure 3.9: Photo realistic render of the nal air quality monitoring device.

The notable changes from the prototype design are:

| Mechanism for self-levelling changed to two-axis design.
| Battery capacity upgraded to 6600mAH
| Custom PCB for electronics and sensors
| Electronics casing updated to multiple mass-producible components as opposed to single 3d printed structure.

An exploded-view lists all the components that make up the device, and demonstrates the hierarchy of components into an assembly:

11

## PARTS LIST

ITEM | QTY | PART NUMBER

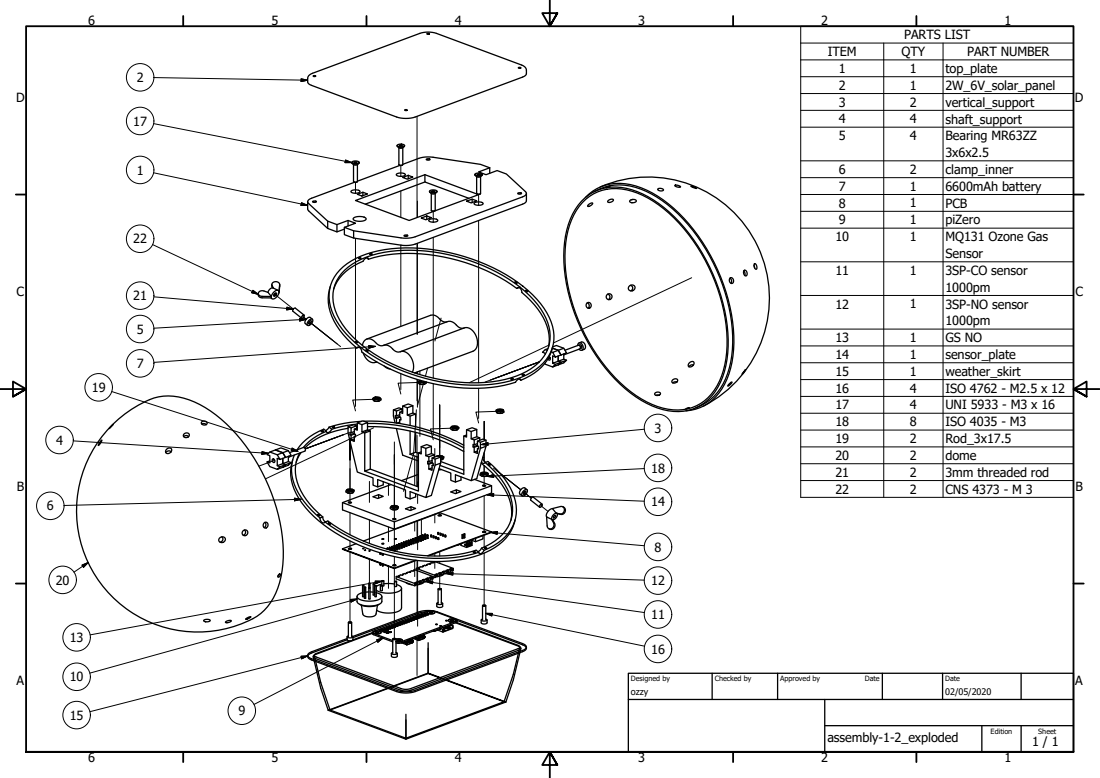
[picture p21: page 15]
CNS 4373 - M 3; assembly-1-2_exploded; ozzy; Designed by; Checked by; Approved by; Date; Edition; Sheet

1 | 1 | top_plate
2 | 1 | 2W_6V_solar_panel
3 | 2 | vertical_support
4 | 4 | shaft_support
5 | 4 | Bearing MR63ZZ 3x6x2.5

6 | 2 | clamp_inner
7 | 1 | 6600mAh battery
8 | 1 | PCB
9 | 1 | piZero
10 | 1 | MQ131 Ozone Gas Sensor

11 | 1 | 3SP-CO sensor 1000pm

12 | 1 | 3SP-NO sensor 1000pm

13 | 1 | GS NO
14 | 1 | sensor_plate
15 | 1 | weather_skirt
16 | 4 | ISO 4762 - M2.5 x 12
17 | 4 | UNI 5933 - M3 x 16
18 | 8 | ISO 4035 - M3
19 | 2 | Rod_3x17.5
20 | 2 | dome
21 | 2 | 3mm threaded rod

Design for Manufacture
The form and material of parts have been carefully considered to provide the required characteristics whilst being mass producible with a simple method for manufacture to reduce cost. Each custom made part has its manufacturing method detailed numbering is per the exploded view:
| Item 1: Top plate is laser cut from 6mm acrylic. 6mm is a standard thickness of the acrylic sheet, this manufacturing method is very adaptable allowing design changes to be incorporated without any expensive re-tooling. This manufacturing could be easily transferred to injection moulding once sucient production throughput is required. Post-processing requires countersinking for screw heads, this can be performed by hand or easily automated with a multiheaded attachment to the laser-cutting machine.
| Item 3: Same as 1.
| Item 4: Laser cut part (same motivation as part 1) in addition high tolerance of laser-cut part allows for interference t reducing amount of adhesive required.
| Item 6: Mild steel was used for the frame as an inexpensive machinable material with sucient stiness. The part can be laser cut from steel sheets or cold rolled and welded depending on production capacity required. Anadosing or powder coating would then be applied to produce weatherproong.
| Item 14: Same as 1.
| Item 15: Weather skirt is a non-load bearing transparent part, deep drawing is a suitable manufacturing method for mass-producing moulded thin parts from transparent materials such a polyethylene.
| Item 20: Dome (two parts), production of this part is likely to be outsourced to a manufacturer specialised in making polystyrene domes. There will be some capital cost for tooling, manufacturing method will be dictated by the supplier but likely to be drawing or vacuum forming, both suitable for mass production.

## 3.2 Software

## 3.3 Prototype Description

[This section should explain the scope of your developed prototype, explain how it works and how it relates to the whole solution. It should clearly demonstrate the interdisciplinary eort in this development. If interdisciplinary development was not possible (see above) it should be clearly stated in this section and explain why it was not possible to exploit some of the expertise from members of your group. This section should also reect how the experience of developing this prototype has conrmed or questioned your whole solution and how it may have changed your view on the whole solution or possibly the challenge in general.]

13

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

## 6. Discussion

## 6.1 Critical reection of proposed solution

[This section should provide an analysis of how the proposed solution meets accountability, responsibility, trans-parency and other ethical concerns. It should honestly reect both the positive and negative impact the solution may have. If the view from the ethical perspective on the solution has changed during the work on this project this section should describe that and explain why the view has changed.]

## 6.2 Future work

[This section should describe immediate and long-term steps after development of the prototype that should be made to achieve the whole solution. If during development of prototype or critical reection of the solution you come to the conclusion that the proposed solution is not useful or not ethically responsible or the overall challenge should not be formulated in this way (see above), this section should clearly state this case and may omit description of future work.]

## 6.3 Teamwork process

[This section should describe how your group organised teamwork, what communication channels and collabo-ration tools you used, how you distributed the tasks, what process allowed you to learn from another discipline during this project.]

## 6.4 Lessons learnt (project)

[This section should reect on the whole project from the teamwork perspective: what was done well, what could have been improved, what would you change if you were to work on another project in this group, what could you recommend for an interdisciplinary team.]

## 6.5 Lessons learnt (per discipline)

[Each member of the group should state what they learnt from another discipline during this project.]

16

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

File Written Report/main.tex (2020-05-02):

%%%%%%%%%%%%%%%%%%%%%%%%%%%%%%%%%%%%%%%%%%%%%%%
%%% Template for lab reports used at STIMA
%%%%%%%%%%%%%%%%%%%%%%%%%%%%%%%%%%%%%%%%%%%%%%%

%%%%%%%%%%%%%%%%%%%%%%%%%%%%%% Sets the document class for the document
% Openany is added to remove the book style of starting every new chapter on an odd page (not needed for reports)
\documentclass[10pt,english, openany]{book}

%%%%%%%%%%%%%%%%%%%%%%%%%%%%%% Loading packages that alter the style
\usepackage[]{graphicx}
\usepackage[]{color}
\usepackage{alltt}
\usepackage[T1]{fontenc}
\usepackage[utf8]{inputenc}
\setcounter{secnumdepth}{3}
\setcounter{tocdepth}{3}
\setlength{\parskip}{\smallskipamount}
\setlength{\parindent}{0pt}

% Set page margins
\usepackage[top=100pt,bottom=100pt,left=68pt,right=66pt]{geometry}

% Package used for placeholder text
\usepackage{lipsum}

% Prevents LaTeX from filling out a page to the bottom
\raggedbottom

%add pdfs
\usepackage{pdfpages}

% Adding both languages
\usepackage[english]{babel}

% All page numbers positioned at the bottom of the page
\usepackage{fancyhdr}
\fancyhf{} % clear all header and footers
\fancyfoot[C]{\thepage}
\renewcommand{\headrulewidth}{0pt} % remove the header rule
\pagestyle{fancy}

% Changes the style of chapter headings
\usepackage{titlesec}
\titleformat{\chapter}
   {\normalfont\LARGE\bfseries}{\thechapter.}{1em}{}
% Change distance between chapter header and text
\titlespacing{\chapter}{0pt}{50pt}{2\baselineskip}

% Adds table captions above the table per default
\usepackage{float}
\floatstyle{plaintop}
\restylefloat{table}

% Adds space between caption and table
\usepackage[tableposition=top]{caption}

% Adds hyperlinks to references and ToC
\usepackage{hyperref}
\hypersetup{hidelinks,linkcolor = black} % Changes the link color to black and hides the hideous red border that usually is created

% If multiple images are to be added, a folder (path) with all the images can be added here 
\graphicspath{ {Figures/} }

% package for subfigures
\usepackage{subcaption}

% Separates the first part of the report/thesis in Roman numerals
\frontmatter

% Stuff for tables:
\usepackage{tabulary}
\usepackage{colortbl}
\usepackage[x11names,table]{xcolor}

%%%%%%%%%%%%%%%%%%%%%%%%%%%%%% Starts the document
\let\cleardoublepage=\clearpage
\begin{document}

%%% Selects the language to be used for the first couple of pages
\selectlanguage{english}

%%%%% Adds the title page
\begin{titlepage}
	\clearpage\thispagestyle{empty}
	\centering
	\vspace{1cm}

	% Titles
	% Information about the University
	{\normalsize CM50304: AI Challenge \\ 
		Department of Computer Science \\
		University of Bath, UK \par}
		\vspace{3cm}
	{\Huge \textbf{Air quality monitoring using an AI-based device}} \\
	%\vspace{1cm}
	%{\large \textbf{xxxxx} \par}
	\vspace{4cm}
	{\normalsize FIRST LAST \\ % \\ specifies a new line
	             FIRST LAST \\
	             FIRST LAST \\
	             FIRST LAST \\
	             FIRST LAST \par}
	\vspace{5cm}
    
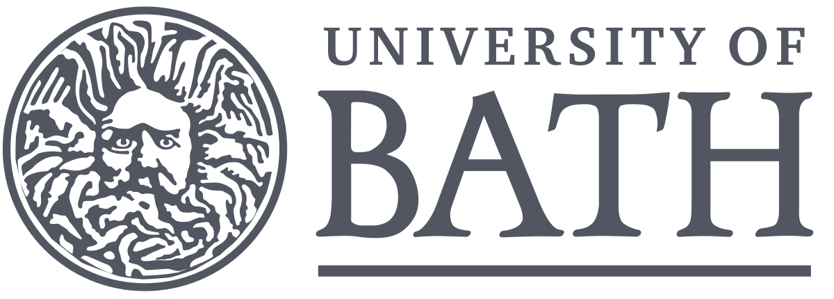
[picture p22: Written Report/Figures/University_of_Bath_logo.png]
    \centering 
    
    \vspace{0.5cm}
		
	% Set the date
	{\normalsize 8th May 2020 \par}
	
	\pagebreak

\end{titlepage}

% Adds a table of contents
\tableofcontents{}

%%%%%%%%%%%%%%%%%%%%%%%%%%%%%%%%%%%%%%%%%%%%%%%%%%%%%%%%%%%%%%%%%%%%%%%%%%%%%%%%%%%%%%%%%%%%
%%%%%%%%%%%%%%%%%%%%%%%%%%%%%%%%%%%%%%%%%%%%%%%%%%%%%%%%%%%%%%%%%%%%%%%%%%%%%%%%%%%%%%%%%%%%
%%%%% Text body starts here!
\mainmatter

\chapter{Summary}\label{chapt:sum}
[\textit{Briefly describe the goal of the project.}]

\chapter{Problem definition and background}
\section{Problem specification}
[\textit{This section should state the challenge, motivate why this challenge is important and explain how it relates to AI.}]

\section{Literature review}
[\textit{This section should review the existing solutions for this challenge and critically analyse ethical issues related to them. It is maybe the case that there are no existing solutions for the chosen challenge. In this case this should be clearly stated and analysed why it is so. If applicable, existing solutions for related challenges may be reviewed here. For example, if your solution is based on solutions for other challenges you should review and critically analyse them in this section.}]

\section{Proposed solution}
[\textit{This section should explain your ambitious solution and why it requires or why it benefits from the interdisciplinary approach. If the solution involves novel research the section should explain why you believe that this research is likely to be successful in the foreseeable future (see above).}]

\chapter{Air quality monitoring device}\label{chapt:doe}
[\textit{Describe the engineering part of the project.}]

\section{Hardware}

\input{./Engineering_hardware/engineering_hardware_section.tex}

\section{Software}
\section{Prototype Description}
[\textit{This section should explain the scope of your developed prototype, explain how it works and how it relates to the whole solution. It should clearly demonstrate the interdisciplinary effort in this development. If interdisciplinary development was not possible (see above) it should be clearly stated in this section and explain why it was not possible to exploit some of the expertise from members of your group. This section should also reflect how the experience of developing this prototype has confirmed or questioned your whole solution and how it may have changed your view on the whole solution or possibly the challenge in general.}]

\chapter{AI model}\label{chapt:model}
[\textit{Describe the AI model in the project}]
\section{Datasets}
\section{Methodology}
\section{Results}
\section{Etc}

\chapter{Social implications}
%\textit{Social science section 
%
%Environmental justice (EJ) emerged in the early 1980s as a frame for understanding iniquities in protection from environmental costs and hazards (Ottinger et al. 2017). Increasingly, however, the EJ research agenda is concerned not just with distributive justice but with procedural or participatory justice, as well as recognition and capabilities (Schlosberg 2007). We have applied the lens of environmental justice to the design of our protype and network of sensors which will generate largescale datasets which will be used to analyse trends, anomalies (etc. – explain).  This will in turn be part of a wider intervention aimed at enabling public participation in scientific practice, deliberation and policy making, and at enhancing accountability in environmental governance, and shaping new opportunities to address environmental injustices. 
%
%Existing accountability tools: 
%
%The Convention on Access to Information, Public Participation in Decision-making and Access to Justice in Environmental Matters (Aarhus Convention) establishes a number of rights (for individuals and associations) with regard to the environment, including: access to environmental information, public participation in environmental decision-making, and a right to hold public authorities accountable for failure to respect rights and obligations under environmental law. 
%
%%https://www.ucl.ac.uk/european-institute/sites/european-institute/files/next_generation_environmental_law_paper_final.pdf
%
% more here 
%
%Air quality as environmental justice
%
%Mitchell and Dorling’s 2003 research into environmental injustices in road traffic-related air pollution in the the UK showed that communities that are most polluted, and which emit the least pollution, tend to be amongst the poorest. In their recent follow-up study, Barnes et al. (2019) found these correlations to be even stronger (see Figure x and Figure y). Moreover, an earlier assumption that poor people contribute substantially to the emissions to which they were exposed (by owning older, more polluting vehicles) was shown to be unfounded.
%
% 
%Figure x Barnes et al. 
% 
%
%Figure y Barnes et al. 
%
%
%When considering the public policy dimensions of their findings, the authors recommended that policy interventions — to address both the underlying air quality problems in the UK, and the highly unequal risks of exposure — ought not to rely predominantly on technological improvements and individual choices. With this in mind, we approach our prototype design alert to the limitations of interventions which focus on individual behaviour change but do not account for wider social dimensions e.g. decisions in land use, economic development and transport planning. This is consistent with the EJ perspective which sees behavioural changes as desirable but insufficient to solve the health problems caused by air pollution (Maturo and Moretti 2018). Shove (2010) similarly argues for UK environmental policy to move away from a model of social change based on ‘ABC’ — attitude, behaviour, and choice — towards more systemic and sociologically informed analyses. 
%
%The relationship between power, inequality and the social construction of environmental problems! Bickerstaff highlights how experience of pollution is related to place - people sometimes ‘Other’ pollution, particularly where they feel disempowered.
%
%
%“The all-too-abstract scientific constructions of air pollution lack any relevance to most people, not only to their culturally embedded understandings but also to the practices by which air pollution science is produced.”
%
%With the system featuring computational techniques that most people will not be familiar with, it is important that the system is not just transparent but, to some degree, explainable (talk about different levels of exploitability). 
%
% One way of addressing this might be to intwine scientific analysis with more deliberative practice. 
%
%Citizen science 
%
%As awareness of ambient air pollution and its negative effects on health has grown, some groups of citizens have engaged in citizen science initiatives to measure and hold authorities accountable for air quality. Citizen science is broadly defined as ‘science developed and enacted by the citizens themselves’ (Irwin 1995). In the context of air quality, citizens have participated in initiatives which use low-cost measuring devices to supplement official measurements (EEA 2019). 
%
%
%Methodology 
%
%If our prototype were to be developed fully, a scoping and feasibility study would be undertaken to identify and understand issues including: 
%
%•	how people would interact with the devices;
%•	how to ensure participation of marginalised groups (recognition and capabilities?);
%•	the most appropriate mechanisms to use the analyses for public accountability; 
%•	
%
%This would also include an options appraisal of possible funding and ownership models. Currently, air quality monitoring sensors in the UK are owned and operated by Defra and local authorities. However, alternative and community based models of ownership may be more desirable, and could address the risk of co-option which (author) identifies in citizen science inititaives. 
%
%References 
%
%EEA. 2019.  
%
%Irwin, A. 1995. 
%
%Maturo A., Moretti V. (2018) Sociological Theories on Air Pollution: Between Environmental Justice and the Risk Society Approach. In: Capello F., Gaddi A. (eds) Clinical Handbook of Air Pollution-Related Diseases. Springer, Cham 
%
%Mitchell, G. and Dorling, D. 2003. An environmental justice analysis of British air quality. Environment and Planning A 2003, volume 35, pages 909- 929 
%
%Ottinger, G., 
%
%Schlosberg 
%
%Shove, Beyond the ABC: climate change policy and theories of social change
%}

\chapter{Discussion}\label{chapt:results}
\section{Critical reflection of proposed solution}
[\textit{This section should provide an analysis of how the proposed solution meets accountability, responsibility, transparency and other ethical concerns. It should honestly reflect both the positive and negative impact the solution may have. If the view from the ethical perspective on the solution has changed during the work on this project this section should describe that and explain why the view has changed.}]

\section{Future work}
[\textit{This section should describe immediate and long-term steps after development of the prototype that should be made to achieve the whole solution. If during development of prototype or critical reflection of the solution you come to the conclusion that the proposed solution is not useful or not ethically responsible or the overall challenge should not be formulated in this way (see above), this section should clearly state this case and may omit description of future work.}]

\section{Teamwork process}
[\textit{This section should describe how your group organised teamwork, what communication channels and collaboration tools you used, how you distributed the tasks, what process allowed you to learn from another discipline during this project.}]

\section{Lessons learnt (project)}
[\textit{This section should reflect on the whole project from the teamwork perspective: what was done well, what could have been improved, what would you change if you were to work on another project in this group, what could you recommend for an interdisciplinary team.}]

\section{Lessons learnt (per discipline)}
[\textit{Each member of the group should state what they learnt from another discipline during this project.}]
\subsection{Person 1}
\subsection{Person 2}
\subsection{Person 3}
\subsection{Person 4}
\subsection{Person 5}

\chapter{Conclusions}

\chapter{Individual contributions}
[\textit{This section should briefly state individual contributions from each team member.}]

\pagebreak

% Adding a bibliography if citations are used in the report
%\bibliographystyle{plain}
%\bibliography{bibliography}
% Adds reference to the Bibliography in the ToC
\addcontentsline{toc}{chapter}{\bibname}

\pagebreak

\chapter*{Appendix A: Code Etc}
% \section{Reference solution data}

\end{document}

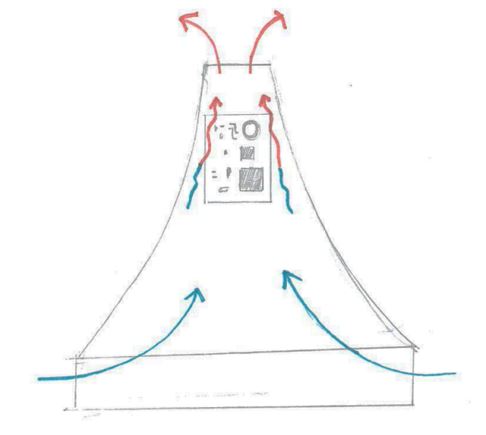
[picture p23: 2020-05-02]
Written Report/Engineering_hardware/Engineering_hardware_Figures/Concept_chimney_b.JPG

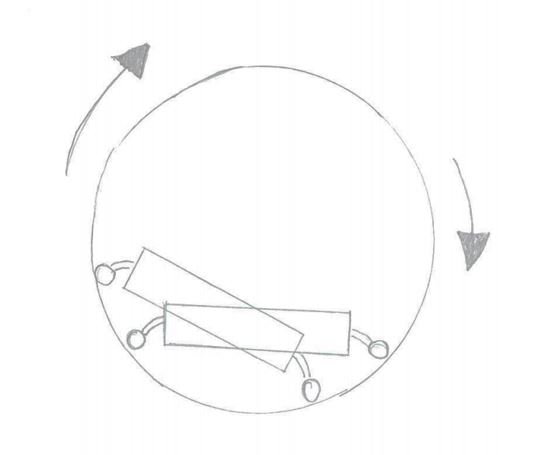
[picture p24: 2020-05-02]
Written Report/Engineering_hardware/Engineering_hardware_Figures/Concept_ball_b.JPG

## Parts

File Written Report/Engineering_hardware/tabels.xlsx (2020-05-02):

 | Requirement | Wish/Deman | Importance | Engineering Specification | Target Value |  | Concepts
 |  |  | (1 low, 5 high) |  |  | Spec No. | A | B | C | D | A | B | C | D
1 | Sensors open to atmosphere | D |  |  |  | 1 | 1 | 1 | 1 | 1
2 | Water Proof | D |  | IP67 |  | 2 | 1 | 1 | 1 | 1
3 | Long battery life | W | 4 | Self powered + battery capacity. | 1 week battery life | 3 | 3 | 5 | 2 | 4 | 12 | 20 | 8 | 16
4 | Easy to set up | W | 5 |  |  | 4 | 5 | 4 | 3 | 1 | 25 | 20 | 15 | 5
5 | Durable | W | 5 | Sustain accidental drops from height | 0.5m | 5 | 5 | 3 | 4 | 3 | 25 | 15 | 20 | 15
6 | Low cost | W | 3 | Component and raw material cost | £200 | 6 | 4 | 5 | 2 | 3 | 12 | 15 | 6 | 9
7 | Recylable | W | 2 |  |  | 7 | 3 | 3 | 3 | 3 | 6 | 6 | 6 | 6
8 | Transparent | W | 4 |  |  | 8 | 5 | 4 | 5 | 3 | 20 | 16 | 20 | 12
9 | Easy to charge | W | 2 | Clear acess to charging port |  | 9 | 3 | 5 | 3 | 4 | 6 | 10 | 6 | 8
10 | Cheap to manufacture | W | 3 | Manufacture and assembly cost | £30 | 10 | 3 | 4 | 2 | 3 | 9 | 12 | 6 | 9
11 | Small form factor | W | 3 | Overall dimmensions | 30x30x30cm | 11 | 4 | 4 | 3 | 2 | 12 | 12 | 9 | 6
 |  |  |  |  |  | weighted sum | 127 | 126 | 96 | 86 | 127 | 126 | 96 | 86

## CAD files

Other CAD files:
Engineering/CAD/Final/assembly-1-2_exploded.dwg
Engineering/CAD/its_just_a_model/prototype air quality monitor case.dwg
Engineering/CAD/Final/OldVersions/assembly-1-2_exploded.0002.dwg
Engineering/CAD/its_just_a_model/OldVersions/prototype air quality monitor case.0004.dwg
Engineering/CAD/Final/OldVersions/assembly-1.0001.ipn
Engineering/CAD/Final/assembly-1.ipn

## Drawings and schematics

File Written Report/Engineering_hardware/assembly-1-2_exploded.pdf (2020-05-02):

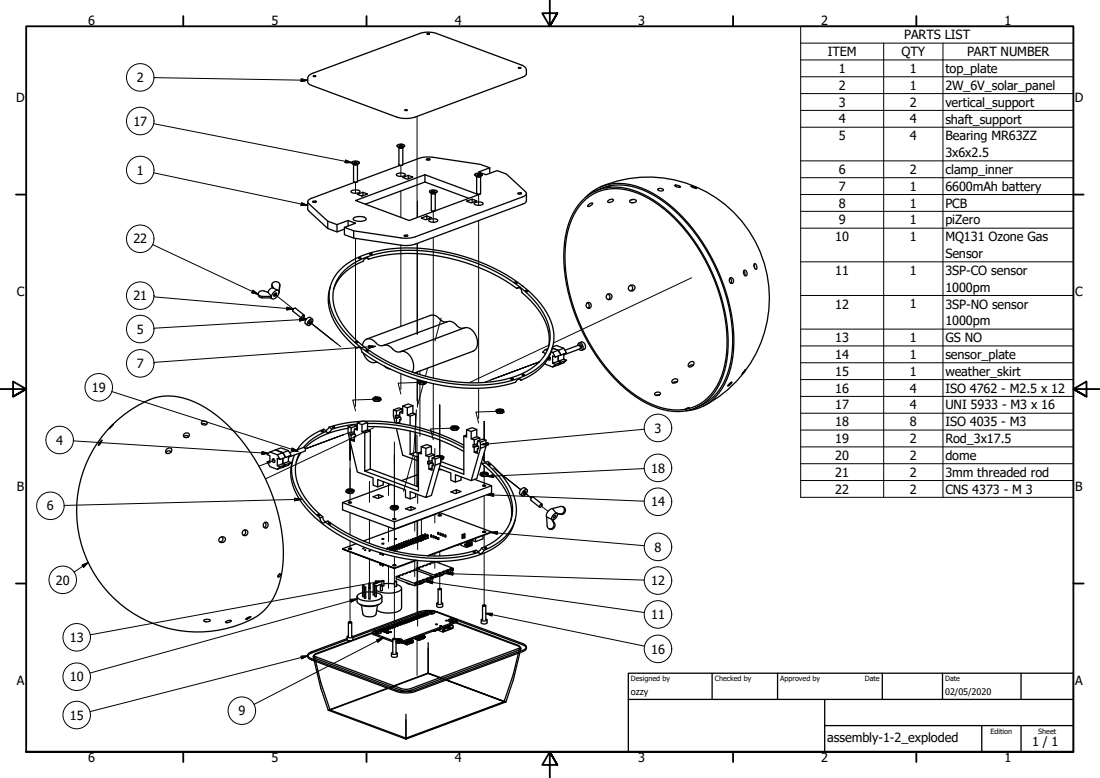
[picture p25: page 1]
vertical_support 4; shaft_support Bearing MR63ZZ 3x6x2.5 5; clamp_inner 7; 6600mAh battery 8; PCB 9; piZero MQ131 Ozone Gas Sensor 10; 3SP-CO sensor 1000pm 11; 3SP-NO sensor 1000pm 12; sensor_plate 15; weather_skirt 16; ISO 4762 - M2.5 x 1

I T E M | Q TY | P A RT N U M B E R
1 | 1 | t o p _ pla t e
2 | 1 | 2 W_ 6 V_ s ola r_ p a n

1 7 | 4 | U N I 5 9 3 3 -M 3 x 1 6
1 8 | 8 | I S O 4 0 3 5 -M 3
1 9 | 2 | R o d _ 3 x 1 7 . 5
2 0 | 2 | d o m e
2 1 | 2 | 3 m m t h r e a d e d r o d
2 2 | 2 | C N S 4 3 7 3 -M 3

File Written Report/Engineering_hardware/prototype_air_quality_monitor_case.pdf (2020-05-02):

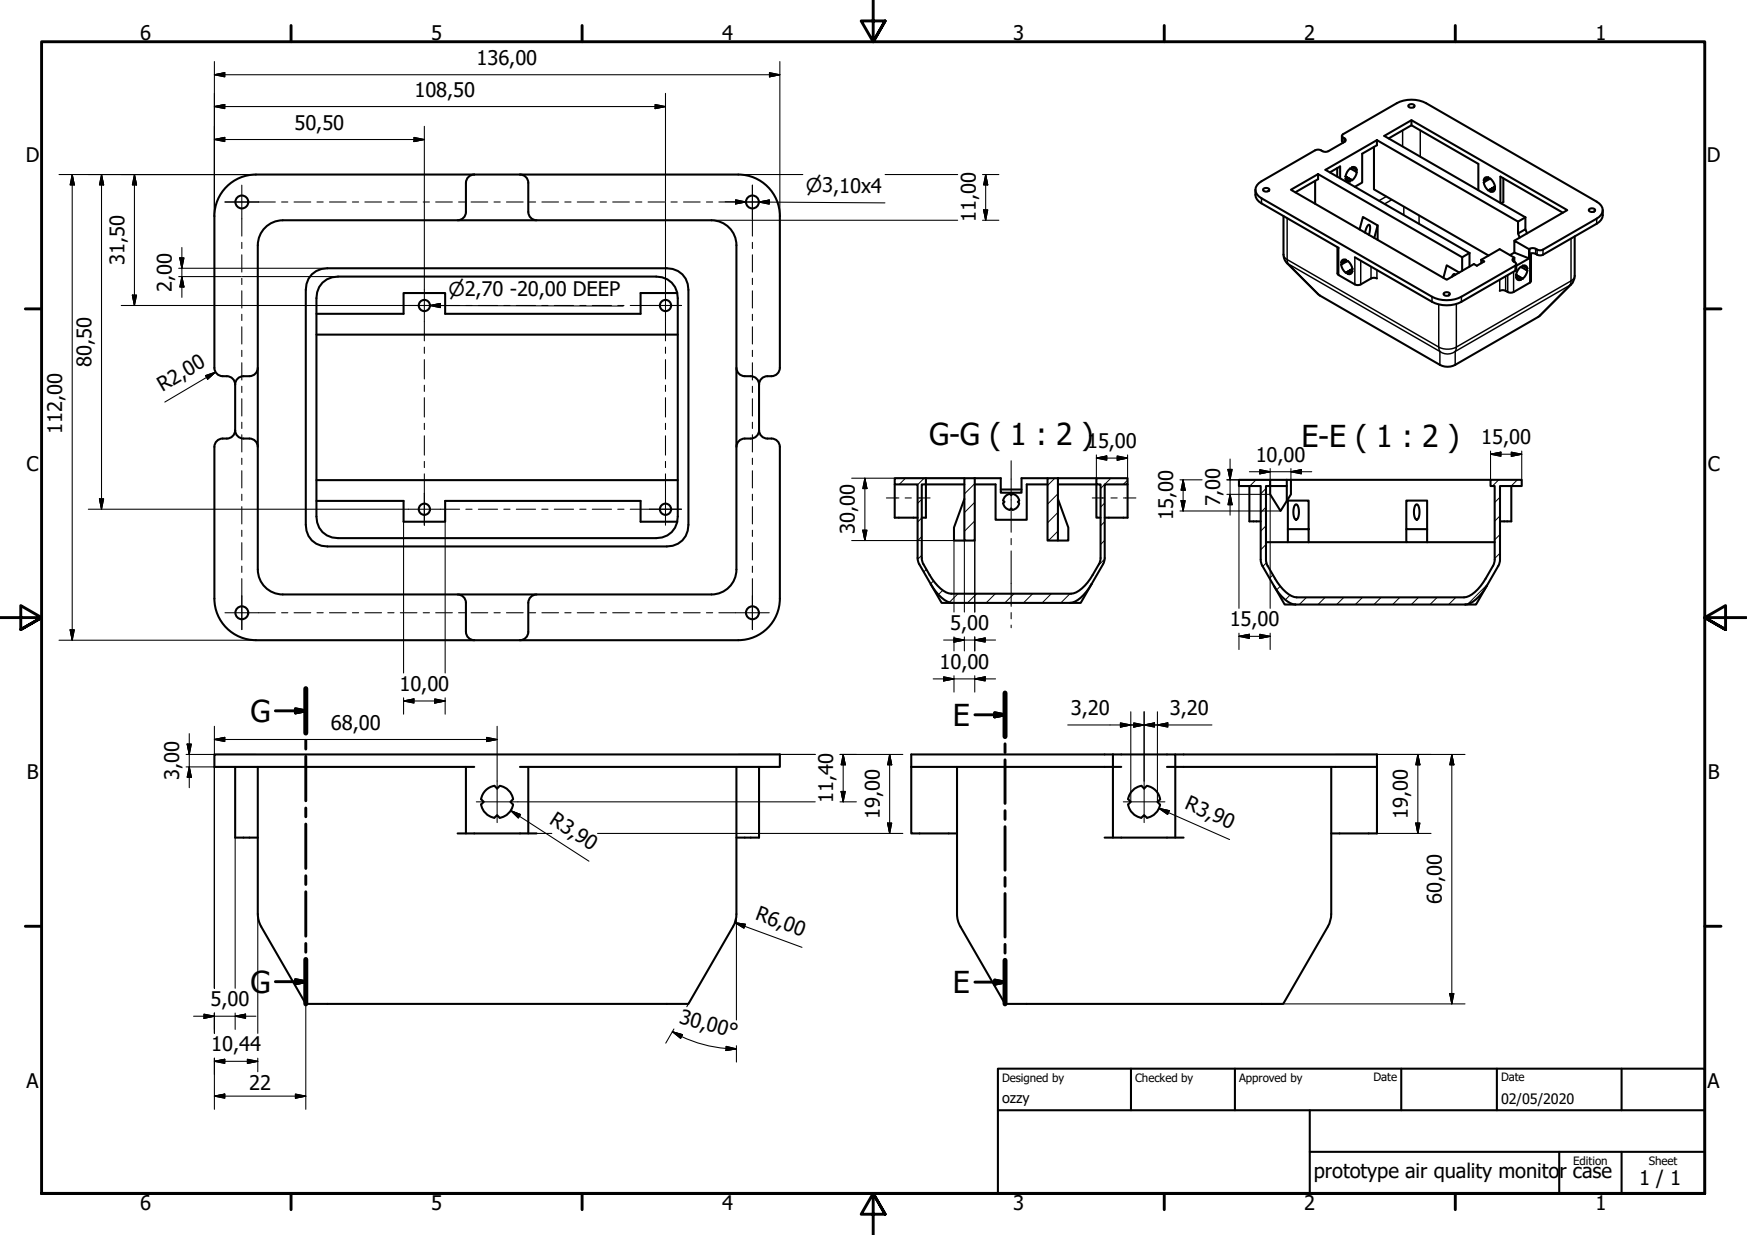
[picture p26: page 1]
Designed by; Checked by; Approved by; Date

prototype air quality monitor case
